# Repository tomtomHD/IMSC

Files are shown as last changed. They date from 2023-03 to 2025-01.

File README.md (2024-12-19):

# IMSC
*Sensor Interface for Soft Detectors in Surgical Simulators*

Thomas Thurner, 2023, <br/>
[thomas.thurner22@gmail.com](mailto:thomas.thurner22@gmail.com) <br/>
 <br/>
[Publication link](https://ieeexplore.ieee.org/abstract/document/10124724)
<br/>
<br/>
**Disclaimer**: <br/>
> The content of the data and files is provided “as is” without any warranty whatsoever, including the accuracy or comprehensiveness. Copyright holder of this document may change the contents of this document at any time without prior notice, and copyright holder disclaims any liability in relation to recipient’s use of this document.
The open source software in this product is distributed in the hope that it will be useful, but WITHOUT ANY WARRANTY; without even the implied warranty of MERCHANTABILITY or FITNESS FOR A PARTICULAR PURPOSE. <br/>

## Software license: MIT
software (C++/QT) license: GNU General Public License <br/>
hardware license: CERN OHL v2 Permissive <br/>
 <br/>
 <br/>
 
## Content:
1. CAD:
   - _SIC_Housing.step_ --> Housing of the Sensory Interface Circuit

3. Circuits: 
   - All Files: KiCad 6.0 Project files (https://www.kicad.org/)

4. Firmware: 
   - EIT_Arduino_V3 --> Folder including all firmware files (two Projects: ArduinoCore, EIT_Arduino_V3), via Microchip Studio 7.0.2542 (https://www.microchip.com/en-us/tools-resources/develop/microchip-studio) 
    - _EIT_Arduino_V3.atsln_ --> Atmel Studio Solution File 
   - _upload_to_proMicro_to_be_edited.bat_	--> File to upload resulting hex-file to microcontroller (to be edited: "Absolute_Path_To...\" needs to be replaced with the Path to the corresponding files) 

5. Software: 
   - Matlab_interface: 
     - _executeIMSC_basic.m_ --> Example code for running the SIC 
     - _IMSC.m_ --> Main file of SIC-class (working name is IMSC (Impedance Multi Sensing Circuit)) 
     - _imscData.m_ --> Data structure class of SIC 
     - _IDSerialComs.m_ --> Get list of COM-devices
   - Python_Interface: 
     - _executeIMSC_basic.py_ --> Example code for running the SIC
     - _executeIMSC_eit.py_ --> Example code for preparing the SIC for EIT
     - _ImpedanceMultiSensingCircuit.py_ --> Main file of SIC-class (working name is IMSC (Impedance Multi Sensing Circuit)) 
   - C++QT_Interface:
     - _impedancemultisensingcircuit.cpp_ --> cpp file
     - _impedancemultisensingcircuit.h_ --> header file

6. _Leakage_Correction_EIT.pdf_ --> Comparisons of the application of compensation strategy (equation 1) to uncompensated calculations by means of an EIT at different frequencies <br/>
 <br/>

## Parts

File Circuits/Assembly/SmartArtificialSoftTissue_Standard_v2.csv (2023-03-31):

ID | Bezeichner | Gehäuse | Stückzahl | Bezeichnung | Anbieter und Referenz
1 | C8,C21,C18,C22,C24,C19,C2,C7,C1,C20 | C_0805_2012Metric_Pad1.18x1.45mm_HandSolder | 10 | 100nF
2 | R42,R33,R36,R39,R38,R43,R48,R40,R44,R37,R32,R49,R34,R45,R46,R35,R31,R47,R41 | R_0402_1005Metric_Pad0.72x0.64mm_HandSolder | 19 | 1M
3 | R23,R15,R6,R56,R2,R53,R1,R3,R25,R16 | R_0402_1005Metric_Pad0.72x0.64mm_HandSolder | 10 | 10k
4 | R52 | R_0402_1005Metric_Pad0.72x0.64mm_HandSolder | 1 | 330
5 | C9,C14,C13,C11,C10 | C_0402_1005Metric_Pad0.74x0.62mm_HandSolder | 5 | 100pF
6 | R61,R64,R60,R62,R63 | R_0402_1005Metric_Pad0.72x0.64mm_HandSolder | 5 | 100k
7 | R51,R50,R17 | R_0402_1005Metric_Pad0.72x0.64mm_HandSolder | 3 | 470
8 | R58,R59 | R_0402_1005Metric_Pad0.72x0.64mm_HandSolder | 2 | 47k
9 | C17 | C_0805_2012Metric_Pad1.18x1.45mm_HandSolder | 1 | 47n
10 | CON2 | IDC-Header_2x03_P2.54mm_Vertical | 1 | Conn_02x03_Odd_Even
11 | J13 | SolderWirePad_1x01_SMD_1x2mm | 1 | Conn_01x01
12 | J3,R5,R19,J2,R7,R24,R4,J1,J4,R18 | R_0402_1005Metric_Pad0.72x0.64mm_HandSolder | 10 | INF
13 | REF** | PinHeader_1x10_P2.54mm_Vertical | 1 | PinHeader_1x10_P2.54mm_Vertical
14 | R65,R67,R55,R54 | R_0402_1005Metric_Pad0.72x0.64mm_HandSolder | 4 | 22k
15 | CON1 | IDC-Header_2x08_P2.54mm_Vertical | 1 | Conn_02x08_Odd_Even
16 | D4 | LED_0805_2012Metric_Pad1.15x1.40mm_HandSolder | 1 | LED_blue
17 | IC1 | SOP65P780X200-16N | 1 | AD5933WYRSZ-REEL7
18 | J5,J9,J8,R_shunt1,J10,J6,J7 | R_0402_1005Metric_Pad0.72x0.64mm_HandSolder | 7 | 0
19 | UC1 | Sparkfun_Pro_Micro | 1 | Sparkfun_Pro_Micro
20 | MUX1,MUX2,MUX3 | RU_28_ADI | 3 | ADG1606BRUZ
21 | Needle1 | Pin_D1.0mm_L10.0mm | 1 | Conn_01x01_Male
22 | D2 | LED_0805_2012Metric_Pad1.15x1.40mm_HandSolder | 1 | LED_yellow
23 | Y1 | ECS2200BX160 | 1 | ECS-2200BX-160
24 | D3 | LED_0805_2012Metric_Pad1.15x1.40mm_HandSolder | 1 | LED_green
25 | CON3 | PinHeader_1x08_P2.54mm_Vertical | 1 | Conn_01x08_Male
26 | AS1 | RU_16_ADI | 1 | ADG1611BRUZ
27 | OPA2,OPA1 | RM_8_ADI | 2 | AD8606ARMZ-REEL
28 | D1 | LED_0805_2012Metric_Pad1.15x1.40mm_HandSolder | 1 | LED_red
29 | J11 | PinHeader_1x06_P2.54mm_Vertical | 1 | Conn_01x06_Male
30 | C23 | C_0402_1005Metric_Pad0.74x0.62mm_HandSolder | 1 | 10pF
31 | IOEX1,IOEX2 | SSOP-28_5.3x10.2mm_P0.65mm | 2 | MCP23017_SS
32 | J12 | PinHeader_1x05_P2.54mm_Vertical | 1 | Conn_01x05_Male

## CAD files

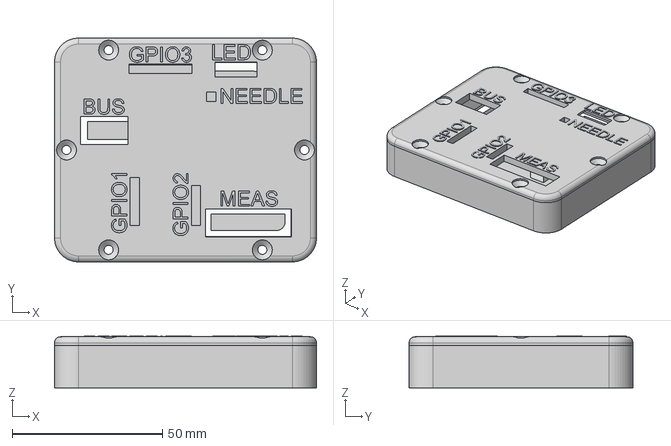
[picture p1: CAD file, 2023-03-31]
CAD/SIC_Housing.step
87.1 x 74.4 x 17.2 mm

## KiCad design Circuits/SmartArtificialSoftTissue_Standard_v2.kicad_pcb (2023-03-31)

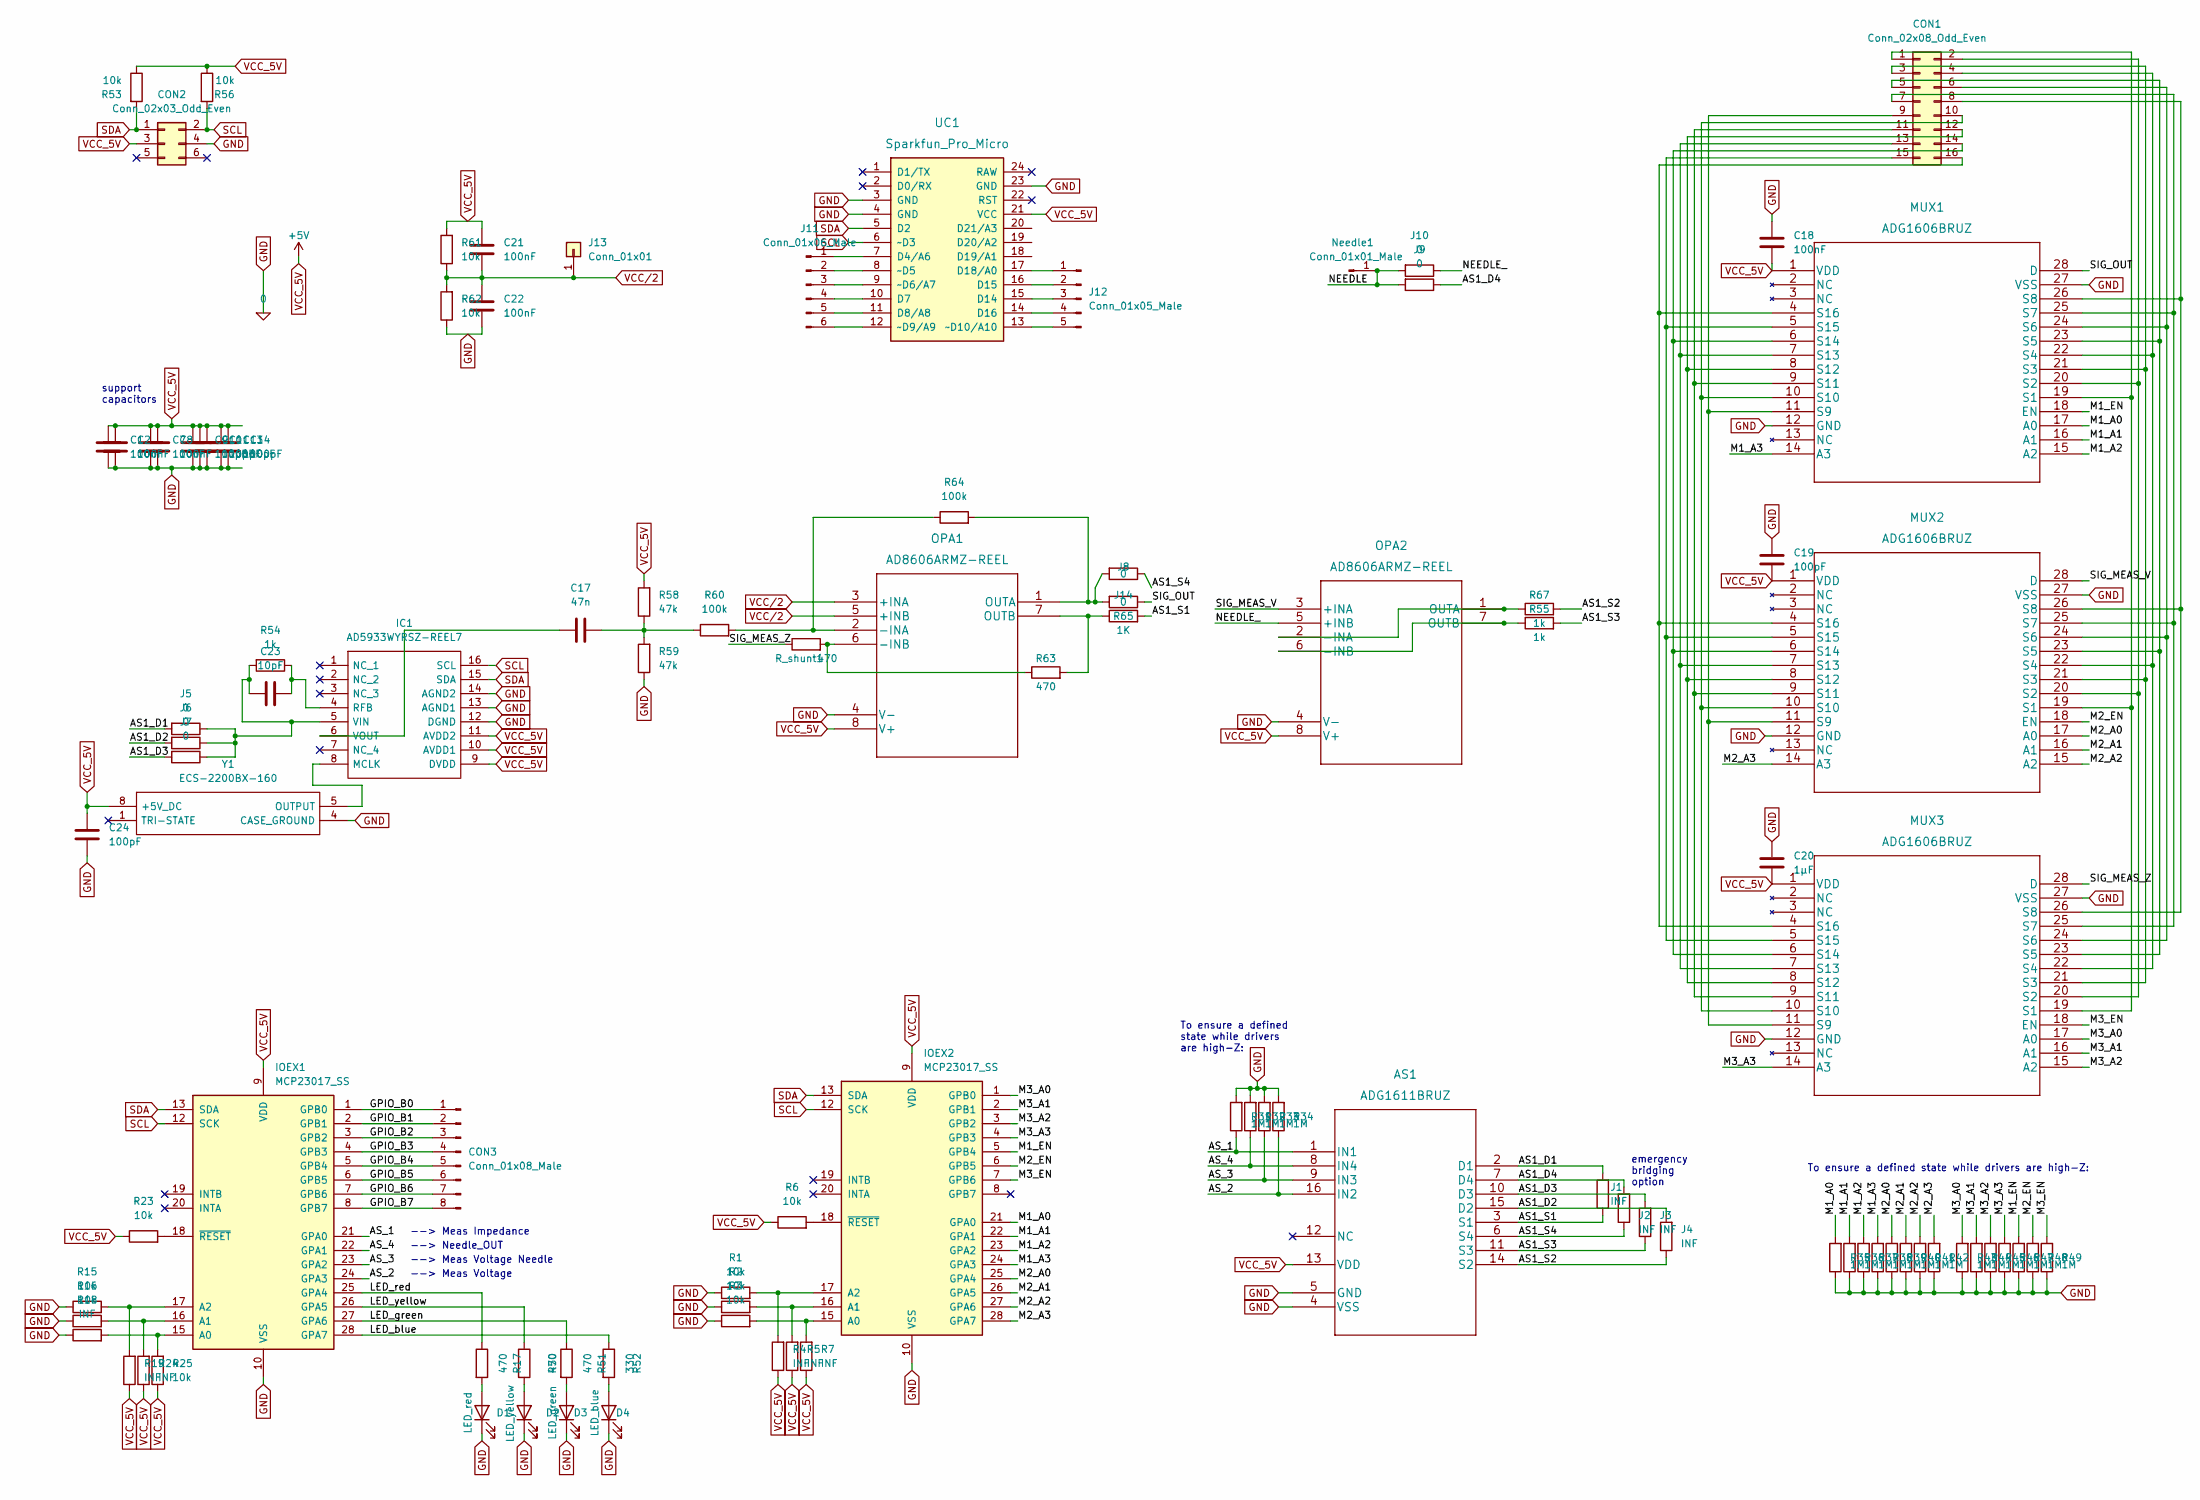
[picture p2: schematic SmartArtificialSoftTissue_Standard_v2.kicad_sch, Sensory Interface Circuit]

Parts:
AS1: ADG1611BRUZ; RU_16_ADI
C1, C2, C7, C8, C18, C21, C22: 100nF; C_0805_2012Metric_Pad1.18x1.45mm_HandSolder
C9, C10, C11, C13, C14: 100pF; C_0402_1005Metric_Pad0.74x0.62mm_HandSolder
C17: 47n; C_0805_2012Metric_Pad1.18x1.45mm_HandSolder
C19, C24: 100pF; C_0805_2012Metric_Pad1.18x1.45mm_HandSolder
C20: 1µF; C_0805_2012Metric_Pad1.18x1.45mm_HandSolder
C23: 10pF; C_0402_1005Metric_Pad0.74x0.62mm_HandSolder
CON1: Conn_02x08_Odd_Even; IDC-Header_2x08_P2.54mm_Vertical
CON2: Conn_02x03_Odd_Even; IDC-Header_2x03_P2.54mm_Vertical
CON3: Conn_01x08_Male; PinHeader_1x08_P2.54mm_Vertical
D1: LED_red; LED_0805_2012Metric_Pad1.15x1.40mm_HandSolder
D2: LED_yellow; LED_0805_2012Metric_Pad1.15x1.40mm_HandSolder
D3: LED_green; LED_0805_2012Metric_Pad1.15x1.40mm_HandSolder
D4: LED_blue; LED_0805_2012Metric_Pad1.15x1.40mm_HandSolder
IC1: AD5933WYRSZ-REEL7; SOP65P780X200-16N; Mouser Part Number 584-5933WYRSZR
IOEX1, IOEX2: MCP23017_SS; SSOP-28_5.3x10.2mm_P0.65mm
J1, J2, J3, J4: INF; R_0402_1005Metric_Pad0.72x0.64mm_HandSolder
J5, J6, J7, J8, J9, J10, J14: 0; R_0402_1005Metric_Pad0.72x0.64mm_HandSolder
J11: Conn_01x06_Male; PinHeader_1x06_P2.54mm_Vertical
J12: Conn_01x05_Male; PinHeader_1x05_P2.54mm_Vertical
J13: Conn_01x01; SolderWirePad_1x01_SMD_1x2mm
MUX1, MUX2, MUX3: ADG1606BRUZ; RU_28_ADI
Needle1: Conn_01x01_Male; Pin_D1.0mm_L10.0mm
OPA1, OPA2: AD8606ARMZ-REEL; RM_8_ADI
R1, R2, R3, R6, R15, R16, R23, R25, R53, R56, R61, R62: 10k; R_0402_1005Metric_Pad0.72x0.64mm_HandSolder
R4, R5, R7, R18, R19, R24: INF; R_0402_1005Metric_Pad0.72x0.64mm_HandSolder
R17, R50, R51, R63: 470; R_0402_1005Metric_Pad0.72x0.64mm_HandSolder
R31, R32, R33, R34, R35, R36, R37, R38, R39, R40, R41, R42, R43, R44, R45, R46, R47, R48, R49: 1M; R_0402_1005Metric_Pad0.72x0.64mm_HandSolder
R52: 330; R_0402_1005Metric_Pad0.72x0.64mm_HandSolder
R54, R55, R67: 1k; R_0402_1005Metric_Pad0.72x0.64mm_HandSolder
R58, R59: 47k; R_0402_1005Metric_Pad0.72x0.64mm_HandSolder
R60, R64: 100k; R_0402_1005Metric_Pad0.72x0.64mm_HandSolder
R65: 1K; R_0402_1005Metric_Pad0.72x0.64mm_HandSolder
R_shunt1: 470; R_0402_1005Metric_Pad0.72x0.64mm_HandSolder
UC1: Sparkfun_Pro_Micro
Y1: ECS-2200BX-160; ECS2200BX160; Mouser Part Number 520-2200BX-160

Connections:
/AS1_D1: AS1.2 (D1), J1.2, J5.2
/AS1_D2: AS1.15 (D2), J4.2, J6.2
/AS1_D3: AS1.10 (D3), J3.2, J7.2
/AS1_D4: AS1.7 (D4), J2.2, J9.1
/AS1_S1: AS1.3 (S1), J1.1, R65.2
/AS1_S2: AS1.14 (S2), J4.1, R67.2
/AS1_S3: AS1.11 (S3), J3.1, R55.2
/AS1_S4: AS1.6 (S4), J2.1, J8.1
/AS_1: AS1.1 (IN1), IOEX1.21 (GPA0), R31.1
/AS_2: AS1.16 (IN2), IOEX1.24 (GPA3), R34.1
/AS_3: AS1.9 (IN3), IOEX1.23 (GPA2), R33.1
/AS_4: AS1.8 (IN4), IOEX1.22 (GPA1), R32.1
/GPIO_B0: CON3.1, IOEX1.1 (GPB0)
/GPIO_B1: CON3.2, IOEX1.2 (GPB1)
/GPIO_B2: CON3.3, IOEX1.3 (GPB2)
/GPIO_B3: CON3.4, IOEX1.4 (GPB3)
/GPIO_B4: CON3.5, IOEX1.5 (GPB4)
/GPIO_B5: CON3.6, IOEX1.6 (GPB5)
/GPIO_B6: CON3.7, IOEX1.7 (GPB6)
/GPIO_B7: CON3.8, IOEX1.8 (GPB7)
/LED_blue: IOEX1.28 (GPA7), R52.1
/LED_green: IOEX1.27 (GPA6), R51.1
/LED_red: IOEX1.25 (GPA4), R17.1
/LED_yellow: IOEX1.26 (GPA5), R50.1
/M1_A0: IOEX2.21 (GPA0), MUX1.17 (A0), R35.2
/M1_A1: IOEX2.22 (GPA1), MUX1.16 (A1), R36.2
/M1_A2: IOEX2.23 (GPA2), MUX1.15 (A2), R37.2
/M1_A3: IOEX2.24 (GPA3), MUX1.14 (A3), R38.2
/M1_EN: IOEX2.5 (GPB4), MUX1.18 (EN), R47.2
/M2_A0: IOEX2.25 (GPA4), MUX2.17 (A0), R39.2
/M2_A1: IOEX2.26 (GPA5), MUX2.16 (A1), R40.2
/M2_A2: IOEX2.27 (GPA6), MUX2.15 (A2), R41.2
/M2_A3: IOEX2.28 (GPA7), MUX2.14 (A3), R42.2
/M2_EN: IOEX2.6 (GPB5), MUX2.18 (EN), R48.2
/M3_A0: IOEX2.1 (GPB0), MUX3.17 (A0), R43.2
/M3_A1: IOEX2.2 (GPB1), MUX3.16 (A1), R44.2
/M3_A2: IOEX2.3 (GPB2), MUX3.15 (A2), R45.2
/M3_A3: IOEX2.4 (GPB3), MUX3.14 (A3), R46.2
/M3_EN: IOEX2.7 (GPB6), MUX3.18 (EN), R49.2
/NEEDLE: J9.2, J10.2, Needle1.1
/NEEDLE_: J10.1, OPA2.5 (+INB)
/SIG_MEAS_V: MUX2.28 (D), OPA2.3 (+INA)
/SIG_MEAS_Z: MUX3.28 (D), R_shunt1.1
/SIG_OUT: J14.1, MUX1.28 (D)
GND: AS1.4 (VSS), AS1.5 (GND), C1.2, C2.2, C7.2, C8.2, C9.2, C10.2, C11.2, C13.2, C14.2, C18.1, C19.1, C20.1, C22.2, C24.2, CON2.4, D1.1 (K), D2.1 (K), D3.1 (K), D4.1 (K), IC1.12 (DGND), IC1.13 (AGND1), IC1.14 (AGND2), IOEX1.10 (VSS), IOEX2.10 (VSS), MUX1.12 (GND), MUX1.27 (VSS), MUX2.12 (GND), MUX2.27 (VSS), MUX3.12 (GND), MUX3.27 (VSS), OPA1.4 (V-), OPA2.4 (V-), R1.1, R2.1, R3.1, R15.1, R16.1, R18.1, R31.2, R32.2, R33.2, R34.2, R35.1, R36.1, R37.1, R38.1, R39.1, R40.1, R41.1, R42.1, R43.1, R44.1, R45.1, R46.1, R47.1, R48.1, R49.1, R59.1, R62.1, UC1.3 (GND), UC1.4 (GND), UC1.23 (GND), Y1.4 (CASE_GROUND)
unnamed: C17.1, IC1.6 (VOUT)
unnamed: C17.2, R58.1, R59.2, R60.1
unnamed: C23.1, IC1.5 (VIN), J5.1, J6.1, J7.1, R54.2
unnamed: C23.2, IC1.4 (RFB), R54.1
unnamed: CON1.1, MUX1.19 (S1), MUX2.19 (S1), MUX3.19 (S1)
unnamed: CON1.2, MUX1.20 (S2), MUX2.20 (S2), MUX3.20 (S2)
unnamed: CON1.3, MUX1.21 (S3), MUX2.21 (S3), MUX3.21 (S3)
unnamed: CON1.4, MUX1.22 (S4), MUX2.22 (S4), MUX3.22 (S4)
unnamed: CON1.5, MUX1.23 (S5), MUX2.23 (S5), MUX3.23 (S5)
unnamed: CON1.6, MUX1.24 (S6), MUX2.24 (S6), MUX3.24 (S6)
unnamed: CON1.7, MUX1.25 (S7), MUX2.25 (S7), MUX3.25 (S7)
unnamed: CON1.8, MUX1.26 (S8), MUX2.26 (S8), MUX3.26 (S8)
unnamed: CON1.9, MUX1.11 (S9), MUX2.11 (S9), MUX3.11 (S9)
unnamed: CON1.10, MUX1.10 (S10), MUX2.10 (S10), MUX3.10 (S10)
unnamed: CON1.11, MUX1.9 (S11), MUX2.9 (S11), MUX3.9 (S11)
unnamed: CON1.12, MUX1.8 (S12), MUX2.8 (S12), MUX3.8 (S12)
unnamed: CON1.13, MUX1.7 (S13), MUX2.7 (S13), MUX3.7 (S13)
unnamed: CON1.14, MUX1.6 (S14), MUX2.6 (S14), MUX3.6 (S14)
unnamed: CON1.15, MUX1.5 (S15), MUX2.5 (S15), MUX3.5 (S15)
unnamed: CON1.16, MUX1.4 (S16), MUX2.4 (S16), MUX3.4 (S16)
unnamed: D1.2 (A), R17.2
unnamed: D2.2 (A), R50.2
unnamed: D3.2 (A), R51.2
unnamed: D4.2 (A), R52.2
unnamed: IC1.8 (MCLK), Y1.5 (OUTPUT)
unnamed: IOEX1.15 (A0), R18.2, R25.2
unnamed: IOEX1.16 (A1), R16.2, R24.2
unnamed: IOEX1.17 (A2), R15.2, R19.2
unnamed: IOEX1.18 (~RESET), R23.2
unnamed: IOEX2.15 (A0), R3.2, R7.2
unnamed: IOEX2.16 (A1), R2.2, R5.2
unnamed: IOEX2.17 (A2), R1.2, R4.2
unnamed: IOEX2.18 (~RESET), R6.2
unnamed: J8.2, J14.2, OPA1.1 (OUTA), R64.2
unnamed: J11.1, UC1.7 (D4/A6)
unnamed: J11.2, UC1.8 (~D5)
unnamed: J11.3, UC1.9 (~D6/A7)
unnamed: J11.4, UC1.10 (D7)
unnamed: J11.5, UC1.11 (D8/A8)
unnamed: J11.6, UC1.12 (~D9/A9)
unnamed: J12.1, UC1.17 (D18/A0)
unnamed: J12.2, UC1.16 (D15)
unnamed: J12.3, UC1.15 (D14)
unnamed: J12.4, UC1.14 (D16)
unnamed: J12.5, UC1.13 (~D10/A10)
unnamed: OPA1.2 (-INA), R60.2, R64.1
unnamed: OPA1.6 (-INB), R63.1, R_shunt1.2
unnamed: OPA1.7 (OUTB), R63.2, R65.1
unnamed: OPA2.1 (OUTA), OPA2.2 (-INA), R67.1
unnamed: OPA2.6 (-INB), OPA2.7 (OUTB), R55.1
SCL: CON2.2, IC1.16 (SCL), IOEX1.12 (SCK), IOEX2.12 (SCK), R56.2, UC1.6 (~D3)
SDA: CON2.1, IC1.15 (SDA), IOEX1.13 (SDA), IOEX2.13 (SDA), R53.2, UC1.5 (D2)
VCC_5V: AS1.13 (VDD), C1.1, C2.1, C7.1, C8.1, C9.1, C10.1, C11.1, C13.1, C14.1, C18.2, C19.2, C20.2, C21.1, C24.1, CON2.3, IC1.9 (DVDD), IC1.10 (AVDD1), IC1.11 (AVDD2), IOEX1.9 (VDD), IOEX2.9 (VDD), MUX1.1 (VDD), MUX2.1 (VDD), MUX3.1 (VDD), OPA1.8 (V+), OPA2.8 (V+), R4.1, R5.1, R6.1, R7.1, R19.1, R23.1, R24.1, R25.1, R53.1, R56.1, R58.2, R61.2, UC1.21 (VCC), Y1.8 (+5V_DC)
VCC/2: C21.2, C22.1, J13.1, OPA1.3 (+INA), OPA1.5 (+INB), R61.1, R62.2

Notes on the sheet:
To ensure a defined state while drivers are high-Z:
--> Needle_OUT
support capacitors
--> Meas Voltage
emergency bridging option
--> Meas Impedance
To ensure a defined state while drivers are high-Z:
--> Meas Voltage Needle

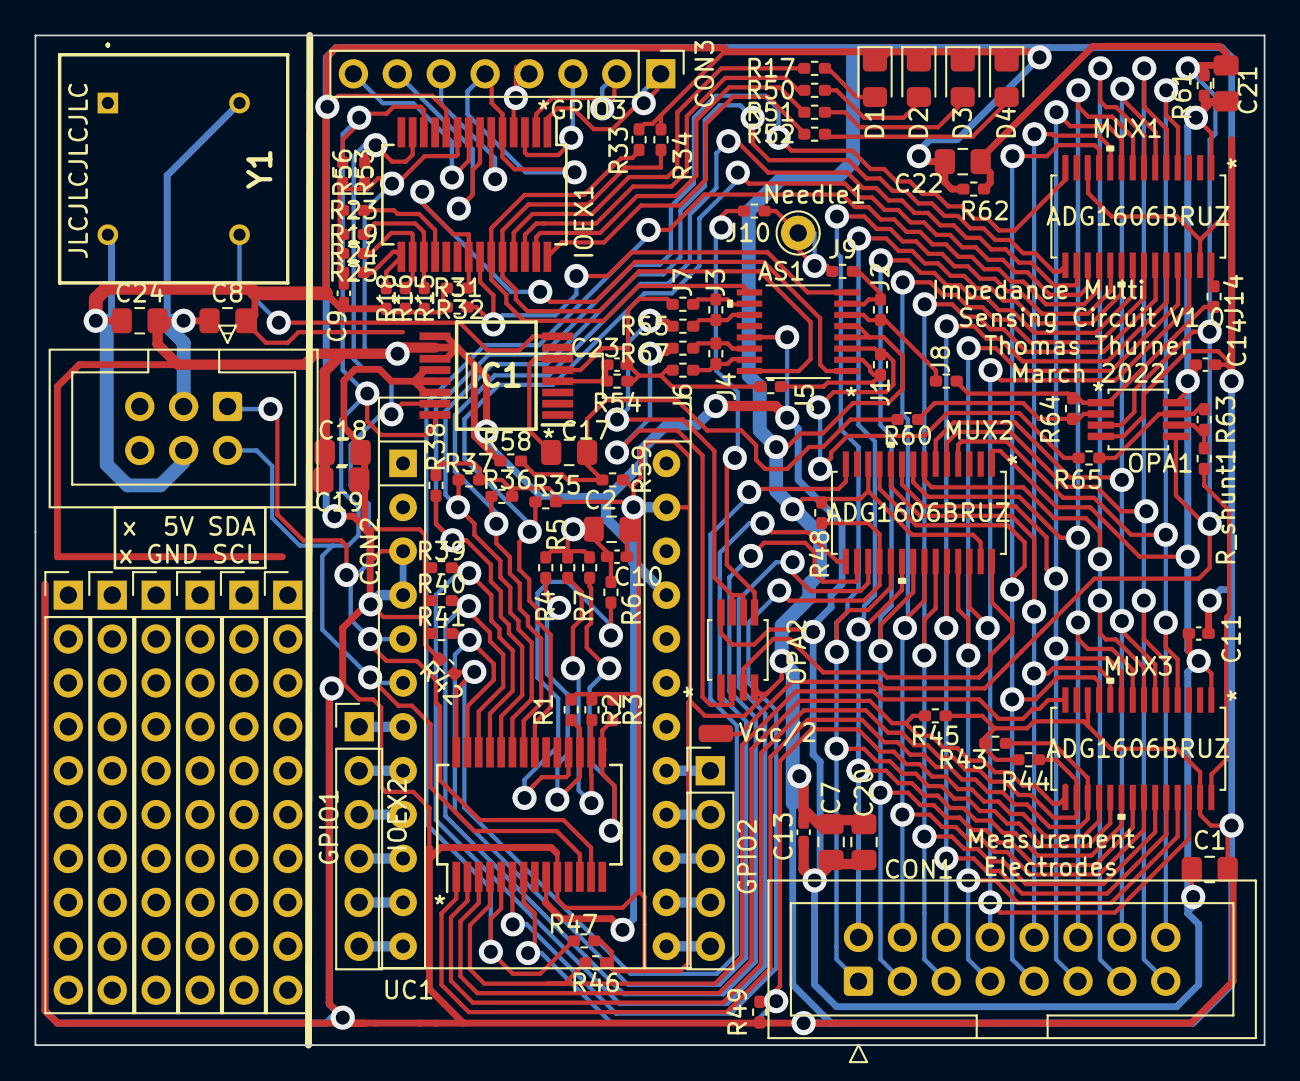
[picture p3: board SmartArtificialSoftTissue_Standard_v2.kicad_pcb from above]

Board: 2 copper layers, 71.1 x 58.4 mm, 101 parts (0 on the bottom side), 99 nets.

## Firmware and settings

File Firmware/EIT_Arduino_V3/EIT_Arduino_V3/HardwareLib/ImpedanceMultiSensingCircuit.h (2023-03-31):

/* 
* ImpedanceMultiSensingCircuit.h
*
* Created: 08.03.2022 23:06:42
* Author: Thomas Thurner
*/


#ifndef __IMPEDANCEMULTISENSINGCIRCUIT_H__
#define __IMPEDANCEMULTISENSINGCIRCUIT_H__

#include "MUX16_CIRCUIT.h"
#include "AD5933s.h"
#include "MCP23017.h"
#include "CircuitDataAndCorrectionValues.h"


//#define DEBUG_MODE




// AD5933 Options:
#define USE_INTERNAL_CLOCK		(false)
#define START_FREQ		(100000)
#define FREQ_INCR		(0)
#define NUM_INCR		(10)
#define MEASURE_NUMBER_PER_STIMULATION (13)
#define SETTLING_TIME_CYCLES (5)	// Waiting cycles until data is collected for the DFT
#define HP_SETTLING_TIME	(3)		// Wait ? ms until Signal is settled to steady state (HP)

// MCP23017 Addresses:
#define MCP23017_MUX_ADDR  (0)		// Address of MCP23017 controlling the Multiplexer
#define MCP23017_MODE_ADDR (1)		// Address of MCP23017 controlling the measurement-Mode, LEDs and GPIOs

// Voltages:
#define SIGNAL_VPP		(1.98)			// V

// Currents:
#define STIMULATION_CURRENT (1)			// mA

// Compensation tolerance:
#define COMPENSATIONTOLERANCE	(10)	// Tolerance; Outside this tolerance, compensation Values get updated and restored into EEPROM
#define COMPENSATION_DETERMINATION_SAFETY_REPETITIONS (3)		// Defines how often the same Result for compensation values has to be measured until they get accepted as valid

// Modes
#define MODE_Data_acquisition_finished	(0)
#define MODE_Magnitude_of_Voltage		(1)
#define MODE_Complex_Voltage			(2)
#define MODE_Magnitude_of_Impedance		(3)
#define MODE_Complex_Impedance			(4)
#define MODE_Magnitude_of_other_Data	(5)
#define MODE_Complex_other_Data			(6)
#define MODE_Magnitude_EIT_Data			(7)

// Gain-factors:
#define GAIN_R			(1.035e-07)						// Gain factor for calculating Impedance with standard circuit, calibrated with 'REF_RESIST = 3300 Ohm'

// Maximum HIGH-Z Values:
#define HIGH_Z_REAL_neg		(-50)
#define HIGH_Z_IMAG_pos		(300)

// ADG1611 Analog Switch:
#define ADG1611_LOG_ON		(0)
#define ADG1611_LOG_OFF		(HIGH)

// IO-Expander MODES PINOUT:
#define PIN_MODE_Z_MEAS_IN	(0)
#define PIN_MODE_V_MEAS_IN	(3)
#define PIN_MODE_NEEDLE_IN	(2)
#define PIN_MODE_NEEDLE_OUT	(1)
#define PIN_LED_RED			(4)
#define PIN_LED_YELLOW		(5)
#define PIN_LED_GREEN		(6)
#define PIN_LED_BLUE		(7)
// IO-Expander GPIO-Port-3 PINOUT:
#define GPIO_PORT_3_PIN_0   (0)
#define GPIO_PORT_3_PIN_1   (1)
#define GPIO_PORT_3_PIN_2   (2)
#define GPIO_PORT_3_PIN_3   (3)
#define GPIO_PORT_3_PIN_4   (4)
#define GPIO_PORT_3_PIN_5   (5)
#define GPIO_PORT_3_PIN_6   (6)
#define GPIO_PORT_3_PIN_7   (7)

// Needle Placeholder:
#define NEEDLE				(16)
//--------------------------------------------------------


//--------------------------------------------------------
// Class for LEDs:
class imsc_LED{
private:
	uint8_t pin;
	bool loglow;
	MCP23017* ioExpander;
	bool state;
public:
	imsc_LED(MCP23017* io_Expander, uint8_t pinIdx, bool logicalLow = LOW);
	~imsc_LED();
	void on();
	void off();
	bool getState();
	void overwrite(bool _state, byte* manipulateByteToSet = nullptr);
};

//--------------------------------------------------------

enum directPrintMode { DirectPRINT_NONE, DirectPRINT_MAGNITUDE, DirectPRINT_COMPLEX };
	
//--------------------------------------------------------
class ImpedanceMultiSensingCircuit
{
//variables

public:
	// Measurement-Pattern:
	uint8_t meas_pattern[MEASURE_NUMBER_PER_STIMULATION];
	
	// Stimulation-Pattern:
	uint8_t stim_pattern;	// Pattern
	uint8_t stim_current;	// Value
	
	// Result Vector of EIT (Voltage) measurement:
	float resultVsEIT[MEASURE_NUMBER_PER_STIMULATION] = {0};
		
	// Results (Temporary storage, can be both, Voltage or Impedance, depending of last measurement):
	float result_Real;
	float result_Imag;
	
	// Compensation Values:
	int16_t compensation_Z_Re;
	int16_t compensation_Z_Im;
	
	int16_t compensation_V_Re;
	int16_t compensation_V_Im;
	
	// Measurement Frequency:
	unsigned long measureFrequency;
		
private:
	// Max. measured DFT-value:
	float maxMeasuredDFT;
	
	// Gain factor for Ue(max)/DFT_value(max)  [ Ue..Output voltage of AD5933; DFT_value..calculated result of DFT in the AD5933]:
	float gain_U;
	// Gain factor for Impedance (1/Referenz_Impedance)/Reference_Magnitude:
	float gain_Z;
	
	// Indicator if signal generator is enabled:
	bool sigGenEnabled;
	
	// Last stimulation current measured:
	float lastMeasuredStimCurrent;
	
	// Temporary raw Data:
	float tempRawData[ELECTRODE_NUMBER+NEEDLE_NUMBER]; // (Electrodes + Needle)
	
	// Array to detect leakage currents (temporary):
	float leakageCurrentCompensationFactorA[ELECTRODE_NUMBER+NEEDLE_NUMBER] = {1};
	/*	At these measures, there is always only one pin/electrode with voltage (all others are highZ):
		All voltages get measured for a single pin stimulation and a Factor f is created to compensate the impact of leakage currents:
	    @Pin0 -> high:   {f0,f1,f2,f3,f4,...fN},
	*/
	
	
//objects
public:
		// Trinity MUX-object pointer:
		MUX16_CIRCUIT* trinityMUX; 
		
		// AD5933-object pointer:
		AD5933s* ad5933ciruit;
		
		// IO-Expander for Modes, LED and GPIO:
		MCP23017* mcp23017_ModeExpander;

private:
		// LED- and Modes:
		imsc_LED* redLED;
		imsc_LED* yellowLED;
		imsc_LED* greenLED;
		imsc_LED* blueLED;
		imsc_LED* analogSwitch_SIG_OUT_NEEDLE;
		imsc_LED* analogSwitch_V_MEAS_NEEDLE;
		imsc_LED* analogSwitch_V_MEAS;
		imsc_LED* analogSwitch_Z_MEAS;
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

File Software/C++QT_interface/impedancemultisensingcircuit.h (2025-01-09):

/*
 * Thomas Thurner
 * Oct. 2024
 *
 * */

// GNU General Public License

// Copyright (C) 2024 Thomas Thurner

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
//
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

#ifndef IMPEDANCEMULTISENSINGCIRCUIT_H
#define IMPEDANCEMULTISENSINGCIRCUIT_H

#include <QObject>
#include <QtSerialPort/QSerialPort>
#include <QSerialPortInfo>
#include <QCoreApplication>
#include <QObject>
#include <Qthread>
#include <QDebug>
#include <QtMath>
#include <vector>
#include <complex>
#include <stdint.h>

#define COM_PORT_DEVICE_NAME "Arduino Leonardo"
#define ELECTRODE_NUMBER 16
#define NEEDLE_NUMBER 1
#define MEASURE_VOLTAGES_PER_STIMULATION 13
#define MEASURE_BUFFER_LENGTH 100
#define MEASURE_BUFFER_VOLTAGES_LENGTH 3000
#define MEASURE_BUFFER_IMPEDANCES_LENGTH 200
#define MEASURE_BUFFER_OTHER_LENGTH 10
#define EIT_DATA_VECTOR_LENGTH 208
#define SERIAL_WAIT_FOR_WRITE_TIMEOUT_MS 100
#define SERIAL_WAIT_FOR_READ_TIMEOUT_MS 100

// Measure modes:
enum measureMode {
    magnitude = 0,
    complex = 1,
};

// EIT modes:
enum eitMode {
    raw = 0,
    corrected = 1,
};

// Poll type (internal):
enum pollType {
         endP = 0,               // Mode0-->Data acquisition finished,
         voltageMagnitude = 1,  // Mode1-->Magnitude of Voltage,
         voltageComplex = 2,    // Mode2-->Complex Voltage,
         impedanceMagnitude = 3,// Mode3-->Magnitude of Impedance,
         impedanceComplex = 4,  // Mode4-->Complex Impedance,
         otherMagnitude = 5,    // Mode5-->Magnitude of other Data,
         otherComplex = 6,      // Mode6-->Complex other Data,
         eitMagnitude = 7,      // Mode7-->EIT Data (Magnitude)
         communicationError = 8,// Mode8-->Communication Error
};

// Define IMSC data structure for single measurement datasets:
struct imscDataset {
    int fromElectrode;
    int toElectrode;
    int measureElectrode;
    float realValue;
    float imagValue;
    float magnitude;

    // Constructor:
    imscDataset(){};
    imscDataset(int fromEl, int toEl, int measureEl, float realV, float imagV, float magV) : fromElectrode(fromEl), toElectrode(toEl), measureElectrode(measureEl), realValue(realV), imagValue(imagV), magnitude(magV) {}
};

// Circular buffer for data storage:
template <typename T>
class CircularBuffer {
public:
    // Constructor (storage with given size)
    CircularBuffer(size_t capacity);

    // Push dataset into Buffer:
    void push(const T& value);
    // Access elements:
    const T& operator[](size_t i) const;
    // Request data length;
    size_t size() const;
    // Get last element:
    const T& back() const;
    // Reset buffer:
    void clear();

    // Data storage:
    std::vector<T> data;

private:
    // Index for circular behavior:
    size_t index;
};

// Define data class for storage:
class IMSCdata {
public:
    // Constructor:
    IMSCdata();
    // Reset all data:
    void clearData();

    // Data types to store:
    CircularBuffer<imscDataset> impedances;
    CircularBuffer<imscDataset> voltages;
    CircularBuffer<imscDataset> other;
    std::vector<imscDataset> eit;
};

struct HardwareError : public std::exception
{
    std::string s;
    HardwareError(std::string ss) : s(ss) {}
    ~HardwareError() throw () {} // Updated
    const char* what() const throw() { return s.c_str(); }
};

class ImpedanceMultiSensingCircuit : public QObject
{
    Q_OBJECT
public:
    // Constructor
    explicit ImpedanceMultiSensingCircuit(QObject *parent = nullptr);
    // Destructor
    ~ImpedanceMultiSensingCircuit();

    // Open serial port connection
    bool begin(const QString& portName = COM_PORT_DEVICE_NAME);

    // Manual start/stop measurement oscillation
    bool manual_Start_MeasurementOscillation();
    bool manual_Stop_MeasurementOscillation();

    // Send stimulation and measurement patterns to hardware
    bool sendStimPatternToHardware(const int stimPattern[ELECTRODE_NUMBER][ELECTRODE_NUMBER] = stdStimPattern);
    bool sendMeasPatternToHardware(const int measPattern[ELECTRODE_NUMBER][MEASURE_VOLTAGES_PER_STIMULATION][ELECTRODE_NUMBER] = stdMeasPattern);

    // Set measurement frequency
    bool setFrequency(uint8_t frequency, bool recalibrate = true);

    // Enable/disable voltage leakage correction
    bool voltageLeakageCorrection(bool onOff);

    // Set pin mode for GPIO ports (not implemented)
    bool gpioMode(int port, std::byte value);

    // Read pin values for GPIO ports (not implemented)
    int16_t gpioRead(uint8_t port);

    // Write values to pins for GPIO ports (not implemented)
    bool gpioWrite(int port, std::byte value);

    // Calibration and data:
    bool calibration();

    // Measure all voltages and impedances
    bool measureAll(measureMode measMod = magnitude);

    // Measure EIT differential voltages
    std::vector<float> measureEIT(eitMode eitMod = raw);

    // Measure voltage between electrodes
    float measureVoltage(int fromEl, int toEl, int measEl, measureMode measMod = magnitude);

    // Measure impedance between electrodes
    float measureImpedance(int fromEl, int toEl, measureMode measMod = magnitude);

    // Check connection:
    bool checkConnection();

    // End communication with hardware:
    bool end();

private slots:
    // Handle serial port errors / disconnections
    void handleSerialPortError(QSerialPort::SerialPortError error);

signals:
    // Signal to emit if a serial port communication error occured:
    void serialPortError();
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

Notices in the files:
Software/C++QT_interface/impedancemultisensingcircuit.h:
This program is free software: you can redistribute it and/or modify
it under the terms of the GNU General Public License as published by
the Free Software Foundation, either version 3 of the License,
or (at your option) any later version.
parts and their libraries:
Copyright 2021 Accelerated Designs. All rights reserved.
